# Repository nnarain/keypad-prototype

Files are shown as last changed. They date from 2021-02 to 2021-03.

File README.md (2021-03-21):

# Keypad prototype




This is a prototype macro keypad. It's based on an Arduino Pro Micro (The version from Sparkfun). It also has room for
and OLED display (over I2C).

The design is a simple key matrix with diodes and should be easily extendable to a full sized keyboard.

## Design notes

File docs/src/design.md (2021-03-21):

# Design Summary

This board support a 3x3 key matrix and an OLED display.

Schematics can be found [here](./_generated/keyboard.pdf).

Key Matrix
----------

A key matrix is used to optimized the number of GPIO required to read key presses. In this case 6 GPIO are needed to
read 9 keys.

Column GPIO are outputs and Row GPIO are inputs (with a pull-up resistor).

Columns are pulled LOW to select the column and Rows are read to determine which keys are pressed.

Diodes are placed together with each switch. This is to prevent "ghosting", where a combination of key presses results
in the micro controller reading key presses for switch that are not pressed.

Micro Controller
----------------

The Pro Micro has more then enough GPIO to support a 9 key matrix and it is very popular in the DIY keyboard space.

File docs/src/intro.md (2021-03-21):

# Introduction

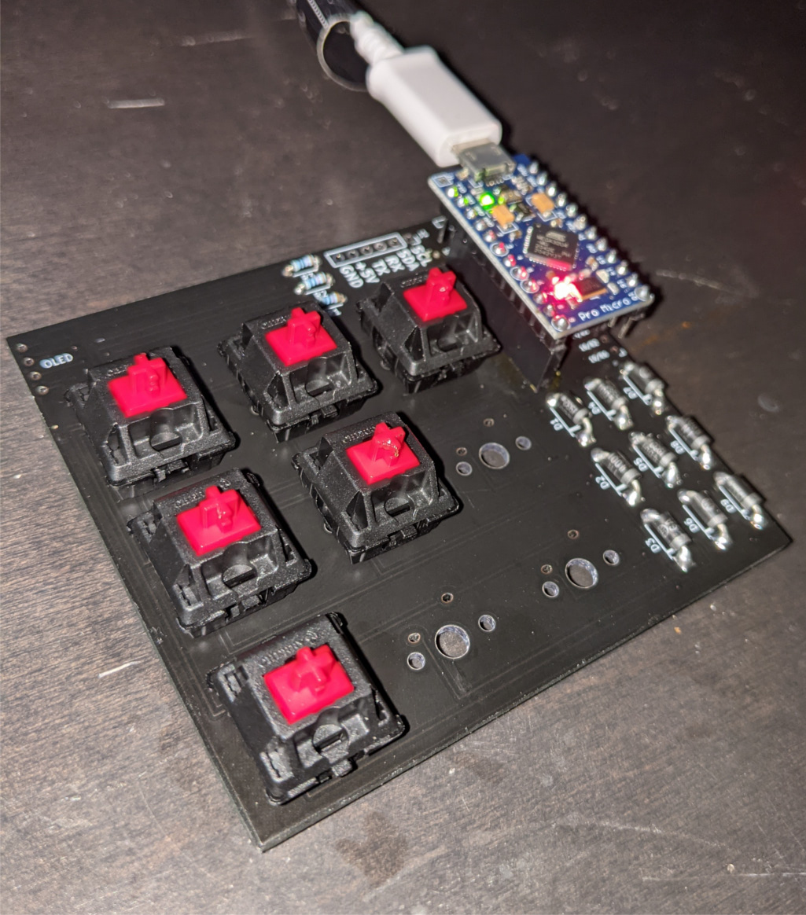
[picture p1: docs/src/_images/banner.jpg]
Image not found


This is a Pro Micro based macro keypad. Intended to test a simple key matrix circuit that can be expanded to a large keyboard in the future.

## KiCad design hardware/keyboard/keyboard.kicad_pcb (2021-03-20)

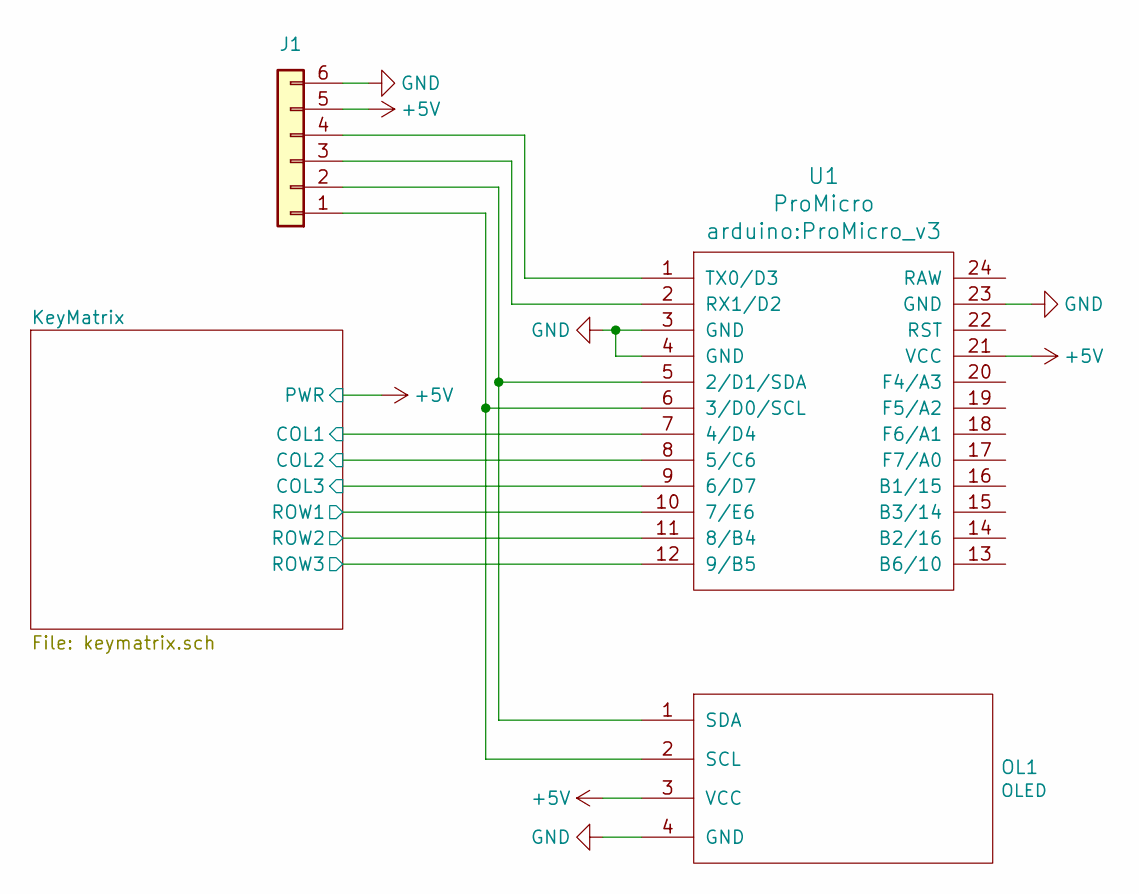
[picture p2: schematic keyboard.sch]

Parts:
J1: Conn_01x06; PinSocket_1x06_P2.54mm_Vertical
OL1: OLED; OLED_v2
U1: ProMicro; ProMicro_v3

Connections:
+5V: J1.5, OL1.3 (VCC), U1.21 (VCC); also elsewhere on the board
/KeyMatrix/COL1: U1.7 (4/D4); also elsewhere on the board
/KeyMatrix/COL2: U1.8 (5/C6); also elsewhere on the board
/KeyMatrix/COL3: U1.9 (6/D7); also elsewhere on the board
/KeyMatrix/ROW1: U1.10 (7/E6); also elsewhere on the board
/KeyMatrix/ROW2: U1.11 (8/B4); also elsewhere on the board
/KeyMatrix/ROW3: U1.12 (9/B5); also elsewhere on the board
GND: J1.6, OL1.4 (GND), U1.3 (GND), U1.4 (GND), U1.23 (GND)
unnamed: J1.1, OL1.2 (SCL), U1.6 (3/D0/SCL)
unnamed: J1.2, OL1.1 (SDA), U1.5 (2/D1/SDA)
unnamed: J1.3, U1.2 (RX1/D2)
unnamed: J1.4, U1.1 (TX0/D3)

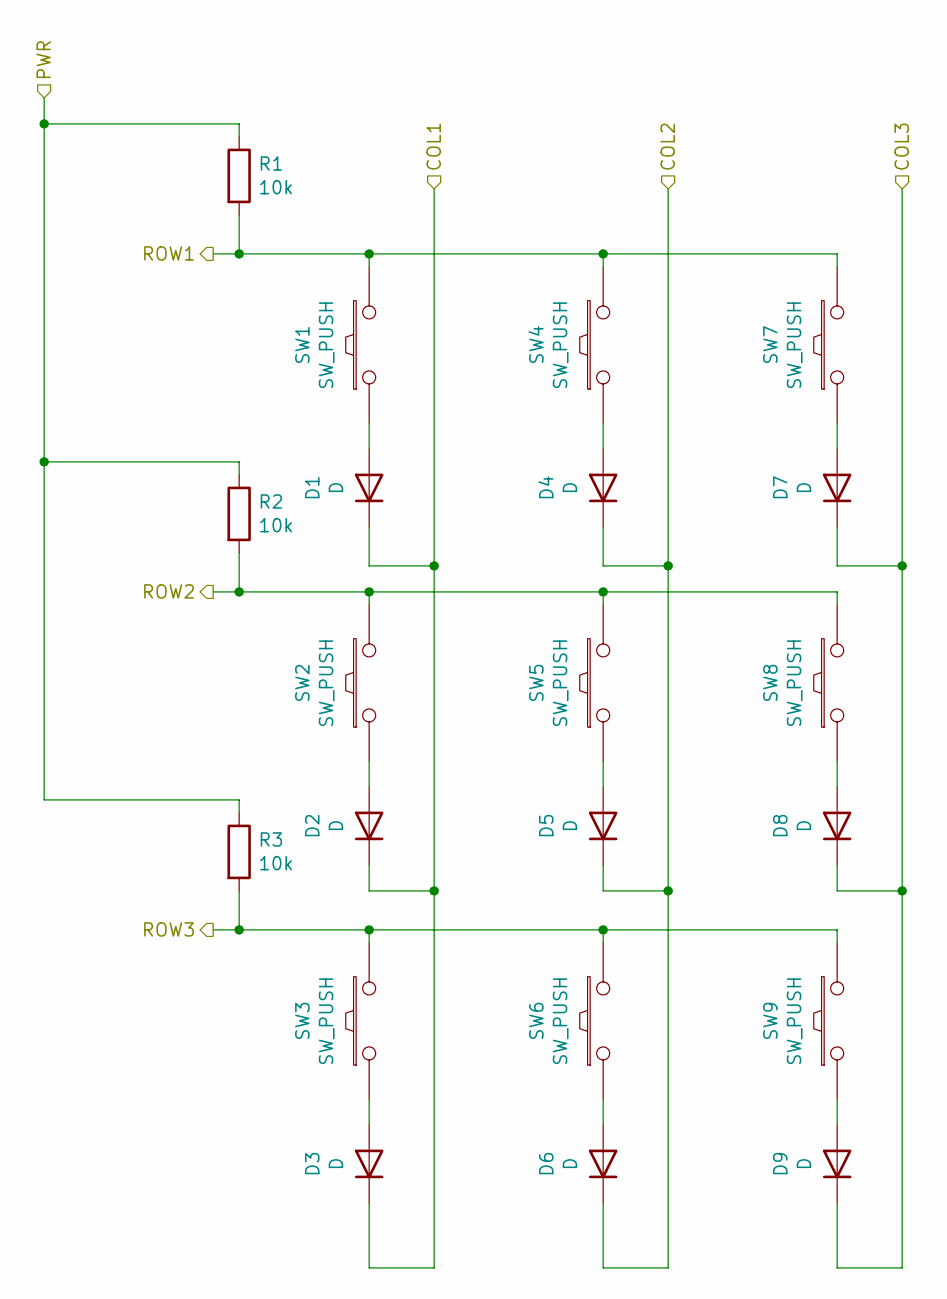
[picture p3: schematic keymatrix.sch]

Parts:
D1, D2, D3, D4, D5, D6, D7, D8, D9: D; D_DO-41_SOD81_P7.62mm_Horizontal
R1, R2, R3: 10k; R_Axial_DIN0204_L3.6mm_D1.6mm_P5.08mm_Horizontal
SW1, SW2, SW3, SW4, SW5, SW6, SW7, SW8, SW9: SW_PUSH; CherryMX_1u

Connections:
+5V: R1.1, R2.1, R3.1; also elsewhere on the board
/KeyMatrix/COL1: D1.1 (K), D2.1 (K), D3.1 (K); also elsewhere on the board
/KeyMatrix/COL2: D4.1 (K), D5.1 (K), D6.1 (K); also elsewhere on the board
/KeyMatrix/COL3: D7.1 (K), D8.1 (K), D9.1 (K); also elsewhere on the board
/KeyMatrix/ROW1: R1.2, SW1.2, SW4.2, SW7.2; also elsewhere on the board
/KeyMatrix/ROW2: R2.2, SW2.2, SW5.2, SW8.2; also elsewhere on the board
/KeyMatrix/ROW3: R3.2, SW3.2, SW6.2, SW9.2; also elsewhere on the board
unnamed: D1.2 (A), SW1.1
unnamed: D2.2 (A), SW2.1
unnamed: D3.2 (A), SW3.1
unnamed: D4.2 (A), SW4.1
unnamed: D5.2 (A), SW5.1
unnamed: D6.2 (A), SW6.1
unnamed: D7.2 (A), SW7.1
unnamed: D8.2 (A), SW8.1
unnamed: D9.2 (A), SW9.1

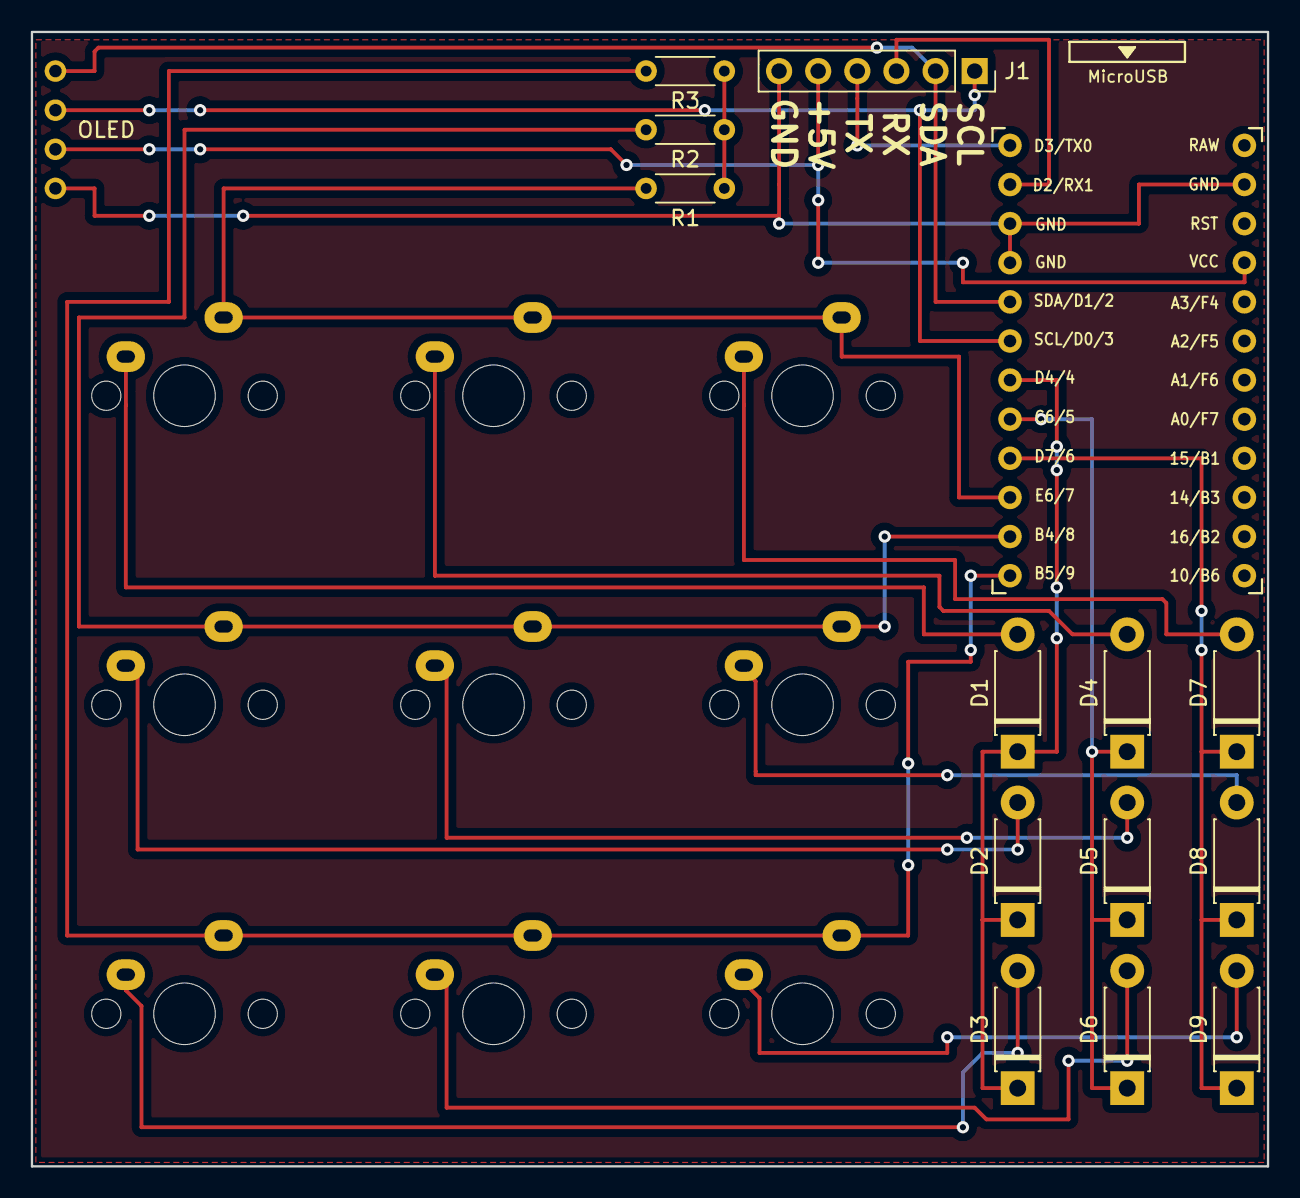
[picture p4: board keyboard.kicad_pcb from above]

Board: 2 copper layers, 80.3 x 73.7 mm, 24 parts (0 on the bottom side), 21 nets.

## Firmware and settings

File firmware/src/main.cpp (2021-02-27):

#include <ftl/platform/platform.hpp>
#include <ftl/logging/logger.hpp>

using namespace ftl::logging;
using namespace ftl::platform;

int main()
{
    Logger<Hardware::UART1> logger{ftl::comms::uart::BaudRate::Rate_9600};
    SystemLogger::instance().setLogger(&logger);

    auto led = Hardware::GPIOB<7>{ftl::GpioState::Output};

    auto col0 = Hardware::GPIOB<2>{ftl::GpioState::Output};
    auto row0 = Hardware::GPIOB<3>{ftl::GpioState::Input};

    col0.reset();

    for(;;)
    {
        if (!row0.read())
        {
            LOG_INFO("Pressed!");
        }
    }

    return 0;
}

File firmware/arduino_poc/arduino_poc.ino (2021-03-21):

/**
  POC Firmware for macro keypad
  @author Natesh Narain <nnaraindev@gmail.com>
*/

#include <Keyboard.h>

#define COL1 4
#define COL2 5
#define COL3 6
#define NUM_COLS 3

#define ROW1 7
#define ROW2 8
#define ROW3 9
#define NUM_ROWS 3

static const int COL_PINS[NUM_COLS] = {COL1, COL2, COL3};
static const int ROW_PINS[NUM_ROWS] = {ROW1, ROW2, ROW3};

static const char BUTTONS[NUM_COLS][NUM_ROWS] = { {'7', '4', '1'}, {'8', '5', '2'}, {'9', '6', '3'} };

void setup() {
  //pinMode(COL1, OUTPUT);
  //pinMode(ROW1, INPUT);

  for (int i = 0; i < NUM_COLS; ++i)
  {
    pinMode(COL_PINS[i], OUTPUT);
  }

  for (int i = 0; i < NUM_COLS; ++i)
  {
    pinMode(ROW_PINS[i], INPUT);
  }

  Serial.begin(115200);
  Keyboard.begin();
}

void loop() {
  for (int col = 0; col < NUM_COLS; ++col)
  {
    // Select the column by pulling it LOW
    digitalWrite(COL_PINS[col], LOW);

    for (int row = 0; row < NUM_ROWS; ++row)
    {
      // Button pressed are a LOW signal
      if (digitalRead(ROW_PINS[row]) == LOW)
      {
        Keyboard.press(BUTTONS[col][row]);
      }
      else
      {
        Keyboard.release(BUTTONS[col][row]);
      }
    }

    //De-select column
    digitalWrite(COL_PINS[col], HIGH);
  }
}

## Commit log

2020-11-18 Initial Keypad prototype
    [comms.sch, keyboard.kicad_pcb, keyboard.sch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]
2021-02-24 update gitignore
    [keyboard.kicad_pcb]
2021-02-25 Update ProMicro footprint
    [keyboard.kicad_pcb, keyboard.sch]
2021-02-27 Added firmware project
    [keyboard.kicad_pcb]
2021-03-20 Fixed broken connections in hierarchy
    [keyboard.kicad_pcb, keyboard.sch]
2021-03-20 Added Arduino keymatrix test
